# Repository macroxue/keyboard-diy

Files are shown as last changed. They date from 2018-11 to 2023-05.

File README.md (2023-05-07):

# Darknight: DIY 60% Split Keyboard
[Ergonomic Design](#ergonomic-design) -
[Layout](#layout) -
[Parts](#parts) -
[Tools](#tools) -
[Construction](#construction) -
[Updates](#updates)

## Ergonomic Design

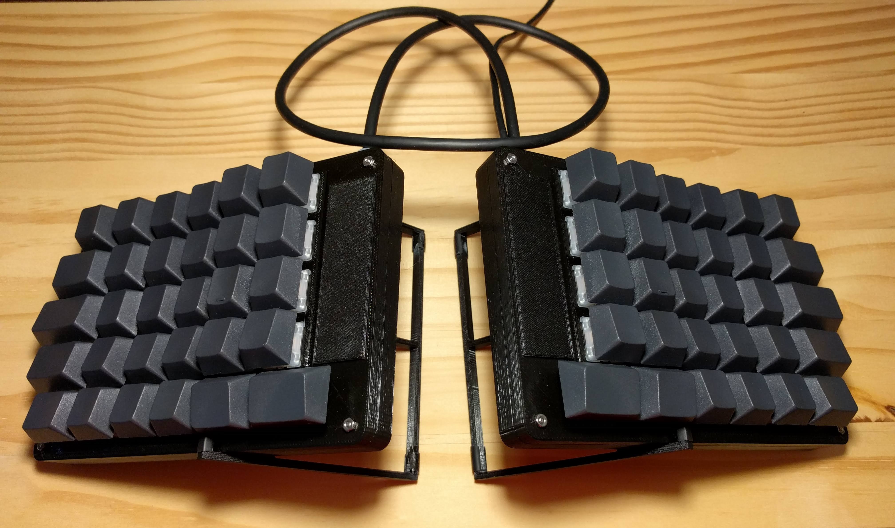
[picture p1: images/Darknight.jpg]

 * 60% keyboard for programmers, especially vim users
 * Symmetric ortholinear / matrix layout
 * Split and tentable
 * Tenting angle quickly adjustable by moving the tenting racks inwards or outwards
 * Mild contour to adapt to finger lengths, with z-staggering and cherry-profile keycaps

## Layout

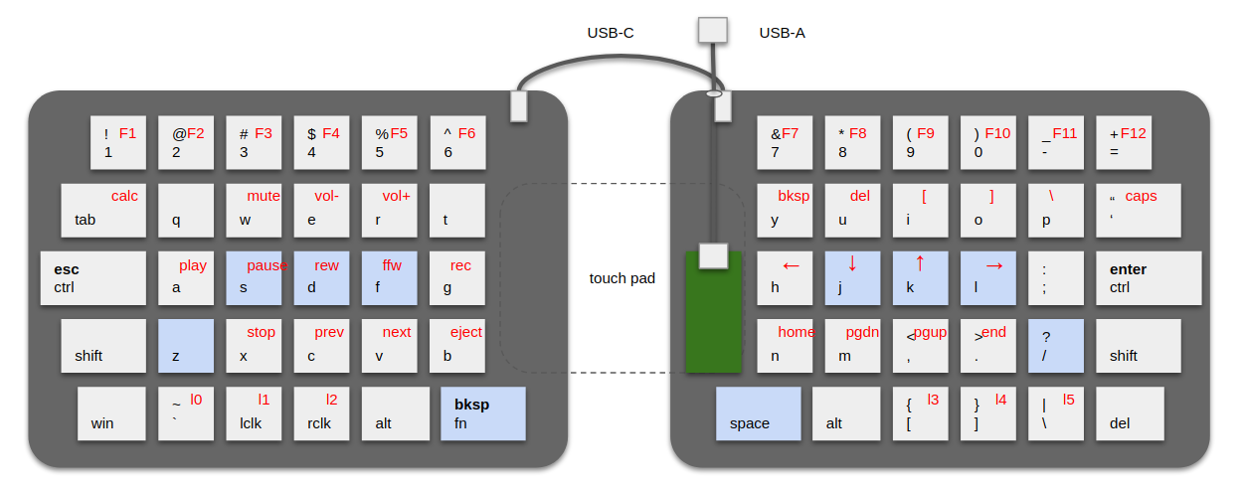
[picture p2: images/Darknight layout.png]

 * Fn key is at the home position of left thumb, which makes cursor moving keys on the right half easily accessible.
 * Ctrl and Fn keys are dual-role modifiers. When tapped, they produce Escape, Enter and Backspace instead. The only downside is that they can’t auto-repeat because they are modifiers when pressed and held. (Hint: Use Ctrl-Backspace to delete words.)
 * Left-click and right-click are at the bottom row of the left half. One can move the mouse with right hand and click on the keyboard with left hand.
 * Brackets and Backslash are at the bottom row of the right half. Single-quote is right above Enter. These changes allow the right half to have only 6 columns and mirror the left half.
 * The blue keys are the home keys of fingers at rest.

## Parts

 * 6 3D-printed case pieces and 2 tenting racks
   * Front piece, back piece and chip cover for each case
   * 8 M2x16 screws and 8 M2 nuts for assembling the cases
 * 60 Gateron red switches (or any Cherry MX compatible switches), plate mounted
 * 60 Blank PBT keycaps from a 120-piece set
   * 60 O-rings for dampening
 * One Teensy 3.2 or Teensy LC as controller
 * For handwired matrix
   * 22 AWG 6-color stranded hook-up wires
   * One 0.25mm copper sheet, 6x6 inches
   * 60 1N4148 diodes
 * One USB-C gen 2 cable (with plugs cut off) for connecting halves.
   See [issue #1](https://github.com/macroxue/keyboard-diy/issues/1).
 * One USB mini cable for connecting the keyboard to computer

## Tools

 * 3D printer
 * Soldering iron
 * Tweezers
 * Wire stripper
 * Heavy duty scissors
 * Knife
 * Nails and hammer
 * Filer
 * Multimeter

## Construction

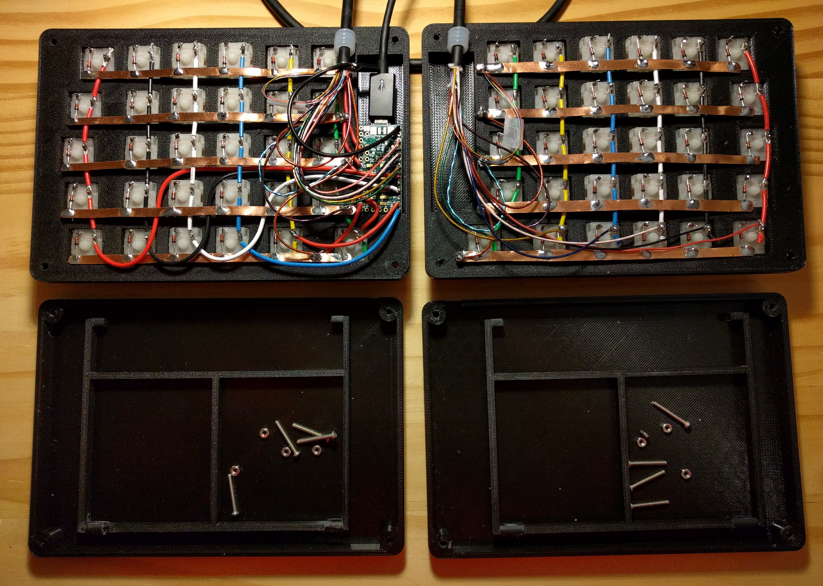
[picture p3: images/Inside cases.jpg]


### Printing cases and tenting racks: 17 hours
 * Print cases: 16 hours with PLA and 12 hours with ABS
 * Print tenting racks: 2 hours with PLA and 1.5 hours with ABS
 * Print chip covers: 10 minutes

3D models in STL format as well as the OpenSCAD file producing them are in [models](https://github.com/macroxue/keyboard-diy/tree/master/models) directory. I use FlashPrint for FlashForge Creator Pro to convert STL files to X3G files before printing them from a SD card.

There are three choices of racks. [rack-rigid.stl](https://github.com/macroxue/keyboard-diy/tree/master/models/rack-rigid.stl) is quick to print and rigid for high tenting angle. [rack-curvy.stl](https://github.com/macroxue/keyboard-diy/tree/master/models/rack-curvy.stl) is good looking but not rigid. [rack-blend.stl](https://github.com/macroxue/keyboard-diy/tree/master/models/rack-blend.stl) is good looking and rigid.

### Installing switches and keycaps: 20 minutes
 * Install switches: 10 minutes
 * Orient switches: pins are at the top half
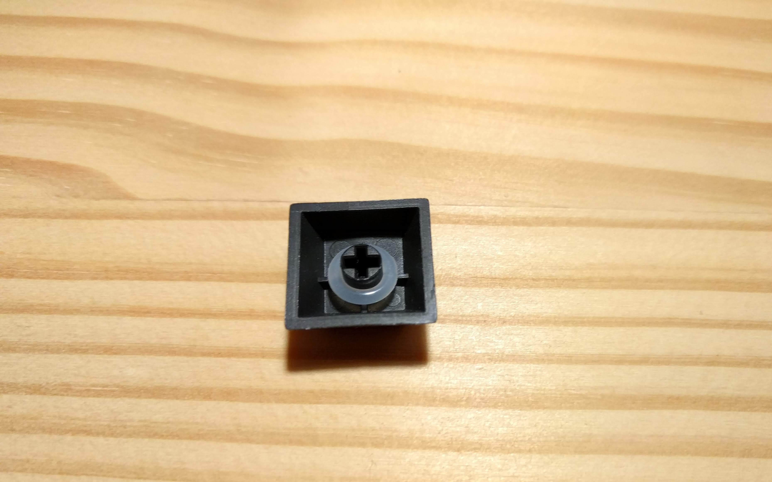
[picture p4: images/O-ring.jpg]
 * Install O-rings and keycaps: 10 minutes 

### Wiring diagrams
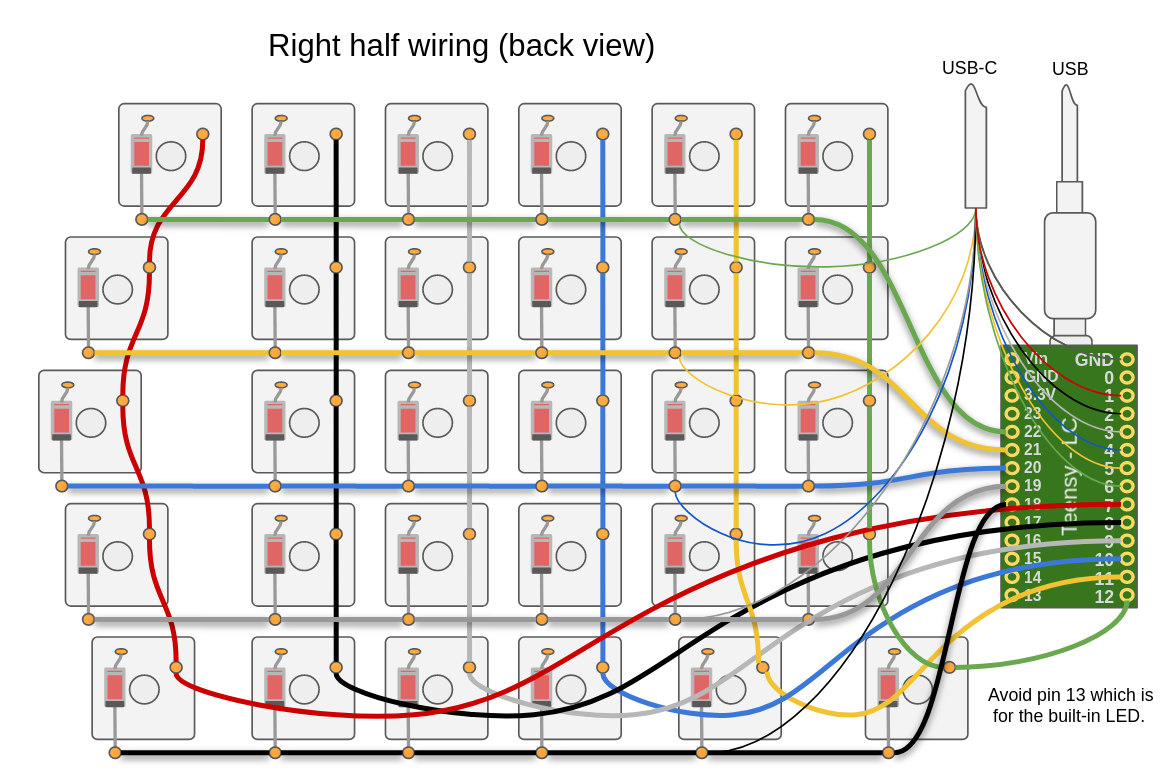
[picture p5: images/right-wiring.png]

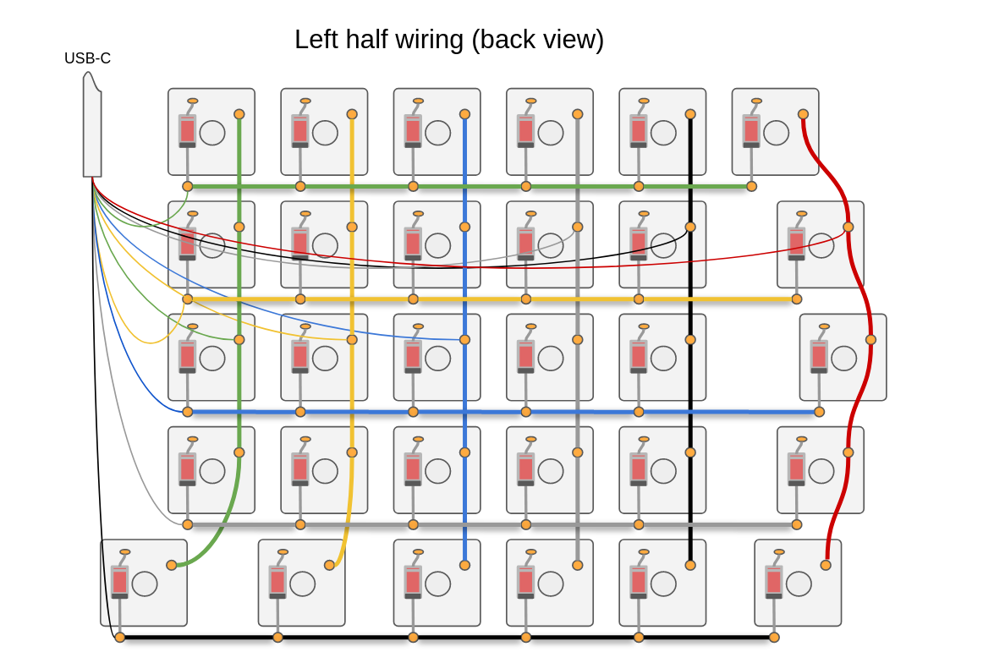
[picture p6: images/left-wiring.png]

 * Use any of the digital pins except pin 13 (LED)
 * Feel free to use pins different than what are in the diagrams

### Wiring switch columns: 2 hours, 1 for each split
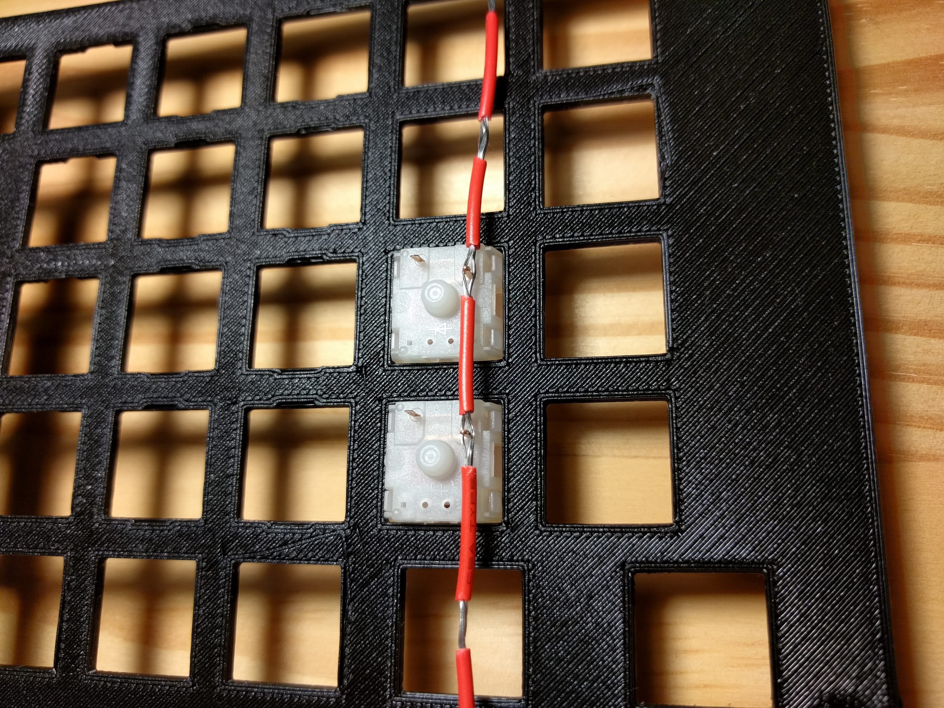
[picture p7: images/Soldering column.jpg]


 * Mark on stranded wire where column pins are
 * Use wire stripper to cut at each mark and 5mm to the right of the mark, i.e. two horizontal cuts 5mm apart at each mark
 * Make a vertical cut between the two horizontal cuts with a knife and remove the insulation to expose the strands
 * Split strands into two parts so a column pin can get through
 * Solder the wire to the pins

### Wiring switch rows and diodes: 4 hours, 2 for each split
 * Cut 3~4mm wide stripe off copper sheet with heavy-duty scissors
 * Mark positions of row pins on the stripe
 * Drill small holes (D~=1mm) at the marks and an extra hole at the end toward the center for wiring the row to the controller
   * Use hammer and nail if no drill at hand
 * Diodes with black terminal oriented downward
   * The black terminal is inserted into a hole on the stripe and bent upward
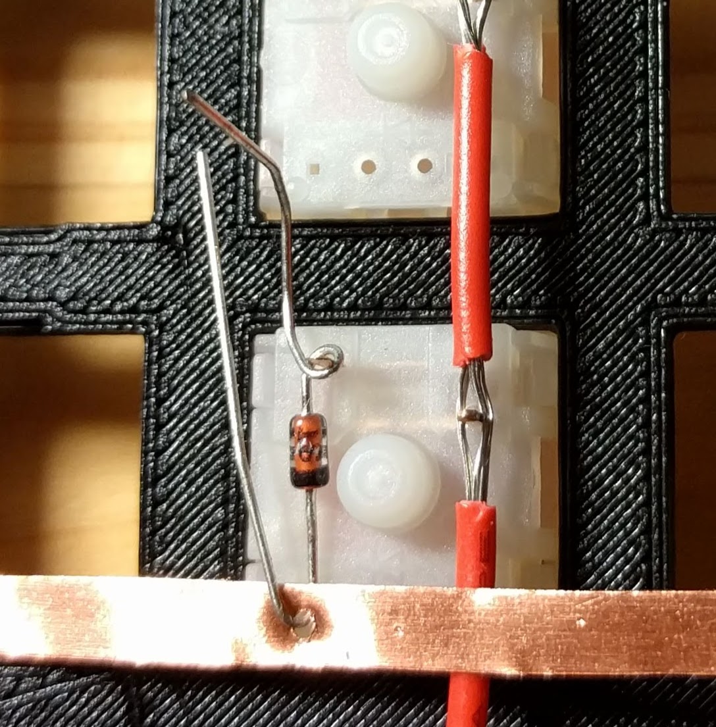
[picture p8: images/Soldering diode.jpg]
   * The other terminal is wrapped around a row pin for at least one complete circle 
 * Make sure the stripe doesn’t touch any exposed part of column wires
 * Solder diodes to row pins
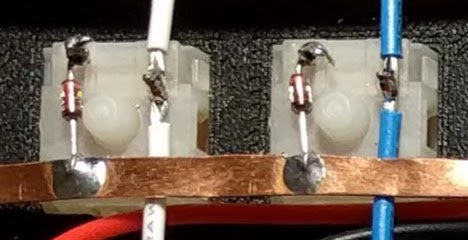
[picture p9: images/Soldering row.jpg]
 * Solder diodes to copper stripe. When solder is applied with the side (not the tip) of the iron touching the stripe, a small “flooding” area of solder creates a strong solder joint. 
 * Cut off extra length of diode terminals

### Testing and fixing: 20 minutes
 * Use a multimeter. Turn the dial to diode sign.
 * Red on column, black on row
 * Press the key at the column-row. Multimeter should read current.

### Connecting the right matrix to controller: 2 hours
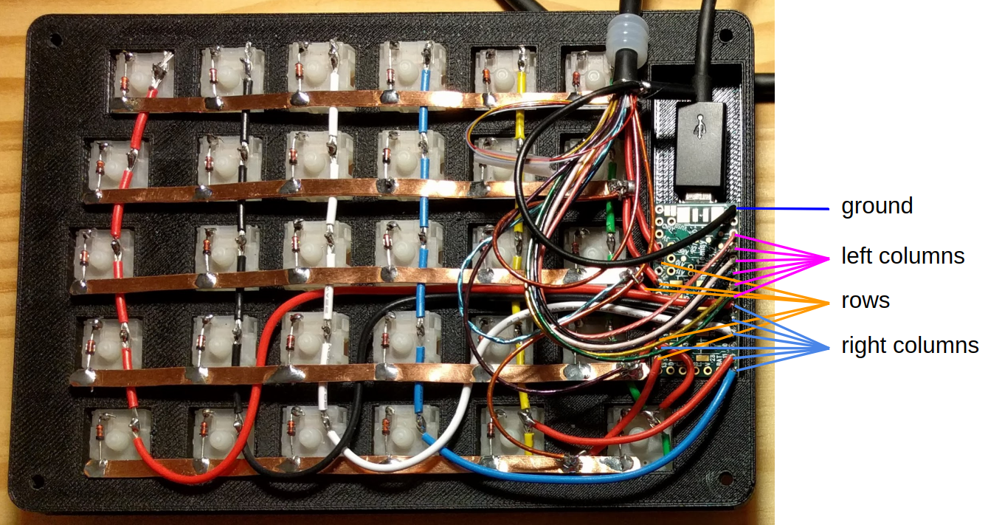
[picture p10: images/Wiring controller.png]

 * Avoid *pin 13* which is for the built-in LED
 * Figure out how to route the wires before soldering
 * Rows are routed with fairly short wires so either solid or stranded wires work
 * Columns are routed with stranded wires for flexibility
 * The controller has its program/reset button facing down so it's accessible without opening the case

### Connecting the left matrix to USB-C: 1 hour
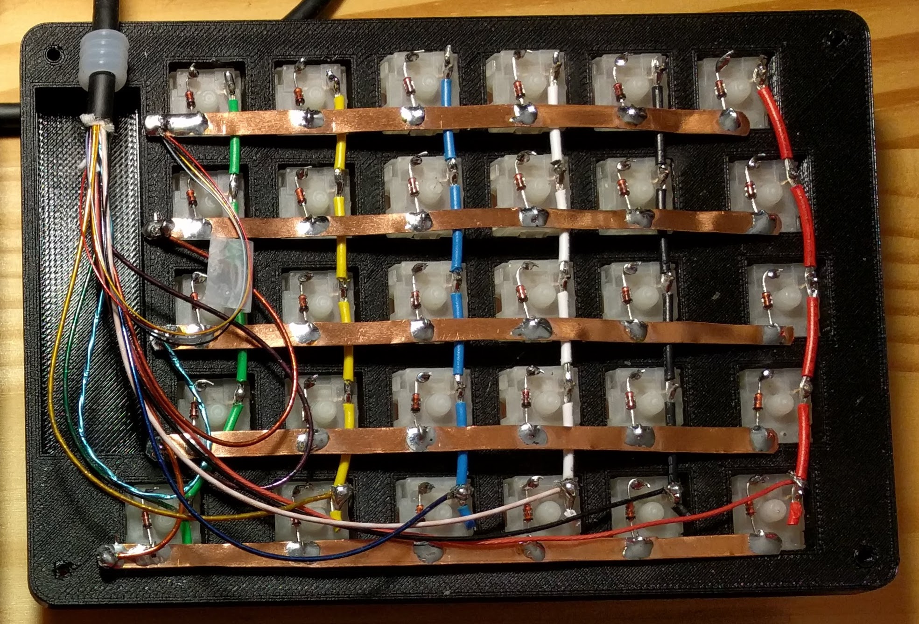
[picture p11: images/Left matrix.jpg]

 * Prepare USB-C cable
   * Cut the plugs off
   * Insert the cable into a few O-rings, which can act as stoppers
   * Mark the length to reach the furthest column
   * Make a round cut at the mark with a knife and remove the insulation
   * Remove the silver-colored mesh and paper wrap to expose wires
   * Observe 4 thin wires and 10 thick wires (2 from a twisted pair)
   * Solder 4 thin wires into one
 * Pin or tape USB-C cable so it doesn’t move around
 * Decide which wire for which column/row
 * Color coding helps, e.g. red USB-C wire to red column wire
 * Cut wires to proper lengths
 * Use soldering iron to remove insulation at the end of each wire
 * Wrap strands around a soldering joint and solder

### Connecting left and right rows: 30 minutes
 * Prepare USB-C cable to expose wires at the other end
 * Pin or tape USB-C cable so it doesn’t move around
 * Cut wires to proper lengths
 * Use soldering iron to remove insulation at the end of each wire
 * Wire rows of the left half to rows of the right half, so logically there are 5 rows.

### Connecting left columns to controller: 30 minutes
 * Ground the silver-colored mesh to GND pin of the controller. Ghost keys can pop up without this.
 * Wire columns of the left half to the controller

### Uploading firmware
 * Note down which controller pin each row/column is wired to. There are 5 rows and 12 columns. Column 0 is where left shift is and column 11 is where right shift is.
 * Plug in USB mini cable to the controller and connect the keyboard to a computer.
 * Download [Teensyduino](https://www.pjrc.com/teensy/teensyduino.html) which extends Arduino to support Teensy controllers.
 * Clone [firmware repo](https://github.com/macroxue/keyboard-firmware) on the computer.
 * Update [keyboards/darknight/darknight.ino](https://github.com/macroxue/keyboard-firmware/blob/master/keyboards/darknight/darknight.ino) with above-noted row pins and column pins.
 * Create a symbolic link in Arduino's libraries directory to the cloned firmware directory.
 * Open `darknight.ino` in Arduino IDE.
 * In the IDE, change "Tools > Board" setting to be "Teensy LC" or "Teensy 3.2/3.1" depending on the controller chip, and change "Tools > USB Type" setting to "Keyboard + Mouse + Joystick".
 * Use "Sketch > Verify/Compile" to make sure the firmware compiles fine, then use "Sketch > Upload" to upload the firmare to the controller.
 * Test the new keyboard!

It happened once that pressing any two keys among Q, W, E, R and T at the same time would also produce Tab. It was fixed by swapping the wires connecting to the first row and the second row. The exact cause is still unknown but a guess is along the line of induced current.

### Closing the cases: 10 minutes
 * Make sure USB mini cable and USB C cable fit in the cable hole
   * May need to enlarge the cable hole with a filer
 * Insert screws and fasten the cases with nuts

### Installing tenting racks: 5 minutes

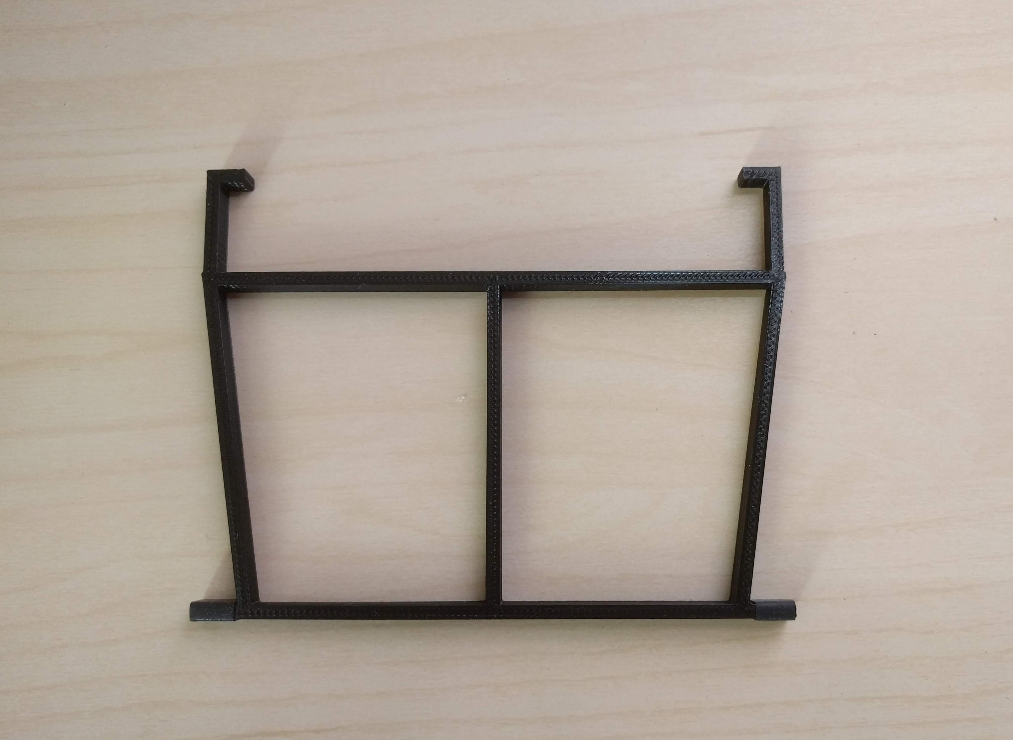
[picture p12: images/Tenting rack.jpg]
 * Cut 8mm pieces from USB-C insulation and insert rack feet into the pieces to increase friction on surface 
 * Slide each case into a rack and adjust tenting angle
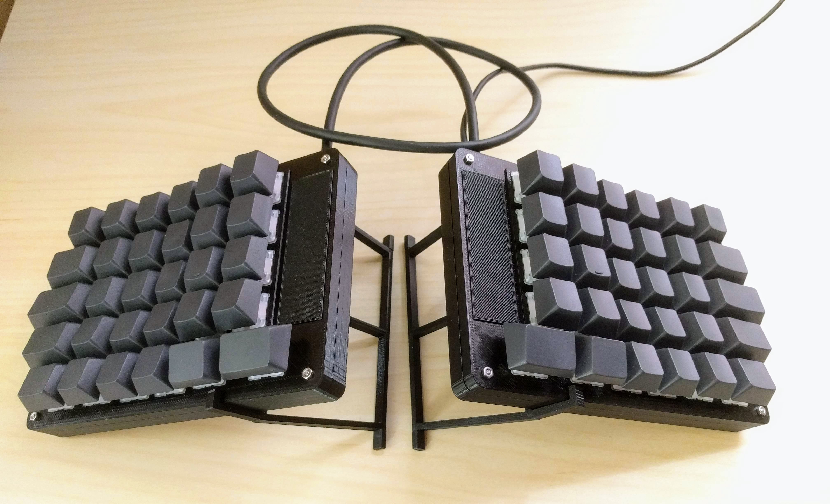
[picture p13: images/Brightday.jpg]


## Updates
### New build on 7/7/2019
Change of color scheme. Maybe call it WhiteKnight.

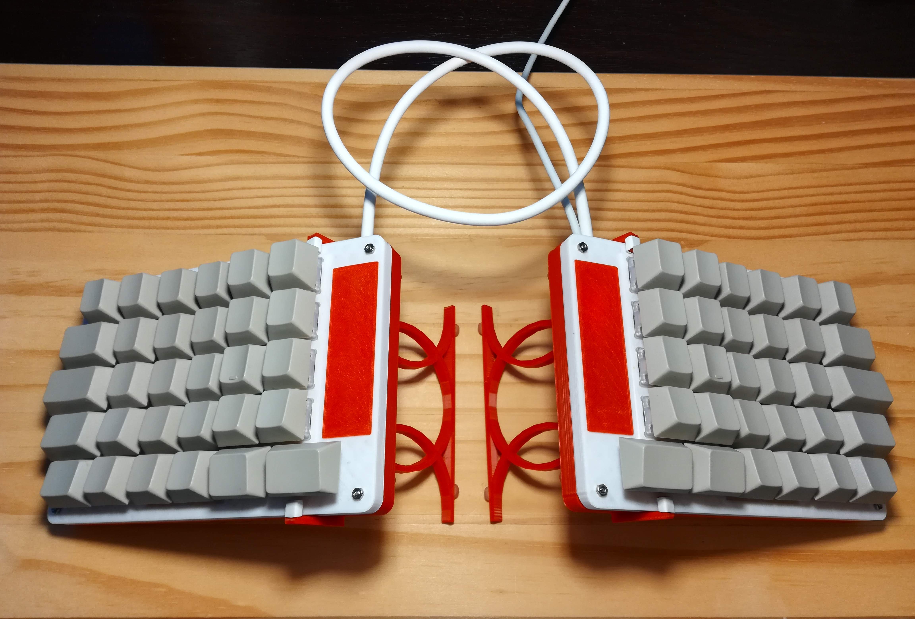
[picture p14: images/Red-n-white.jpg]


### New build on 12/30/2020
What else is better than building another keyboard in these holidays! I call this one RedBaron.

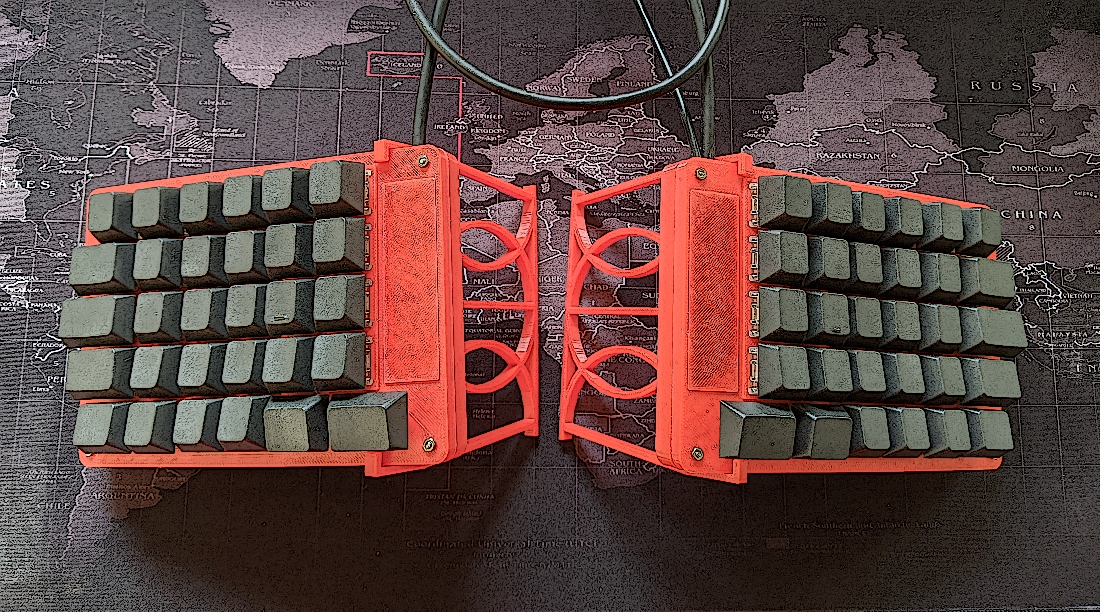
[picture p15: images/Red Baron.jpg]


Now I have three such keyboards, Darknight trapped at work due to the pandemic, WhiteKnight for working at home and RedBaron for personal use.

For this build, I just used stranded wires for the matrix. It turns out to be simpler since the wires can be routed to the controller directly.

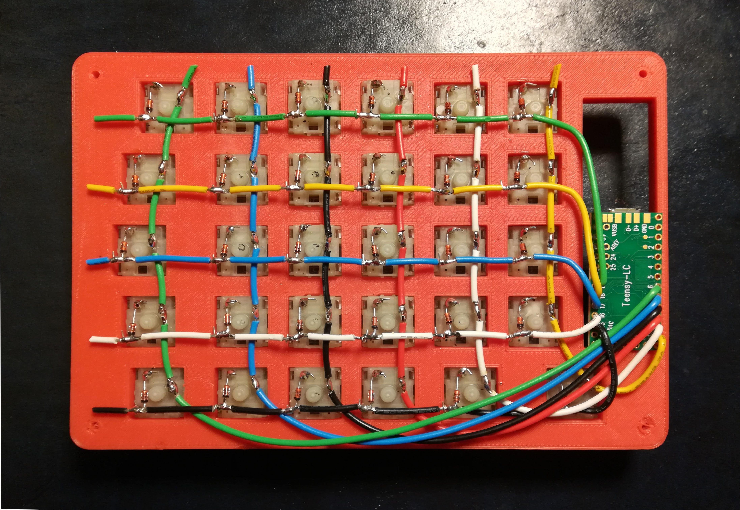
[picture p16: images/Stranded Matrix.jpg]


### High-angle tenting on 11/12/2021

A bridge connecting the two halves turns out to be a good solution for high-angle tenting. The bridge is simply the two tenting racks joined together, with small adjustments in size.

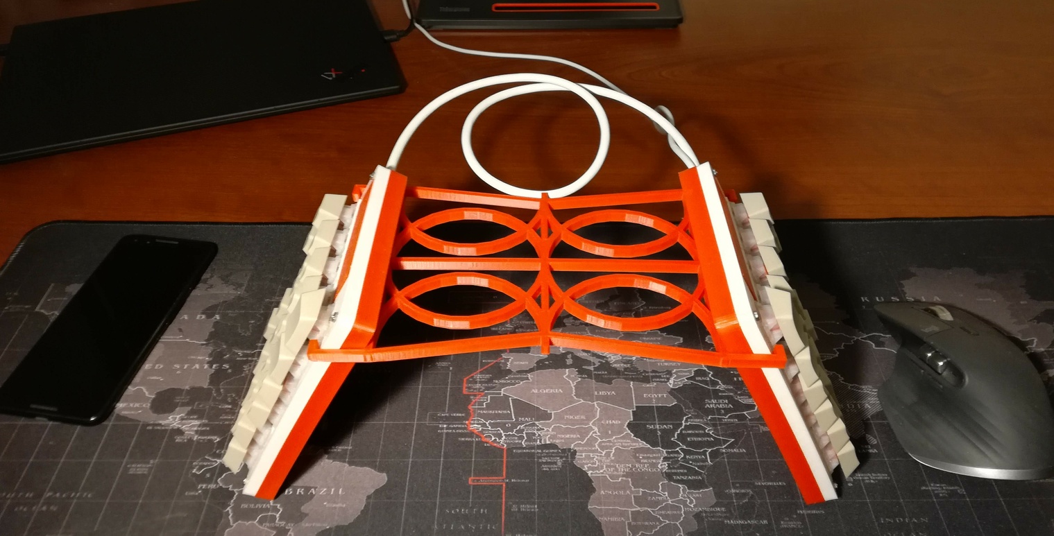
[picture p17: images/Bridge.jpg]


With a little more engineering, the entire structure can be locked by tension so it can be easily moved around.

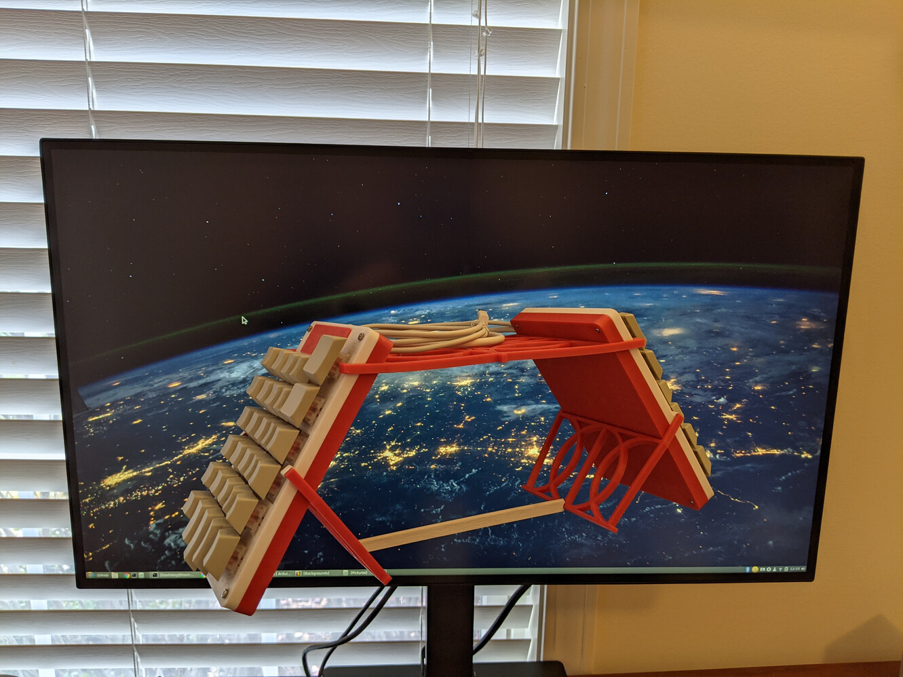
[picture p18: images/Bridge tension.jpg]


### New build on 5/7/2023

Darknight is officially missing in the office during the COVID pandemic. Site maintenance
took it as a company equipment and recycled it. After nearly 4 years of heavy use, Gateron
Red linear switches in WhiteKnight begin to fail. Tangerine is the new replacement build.

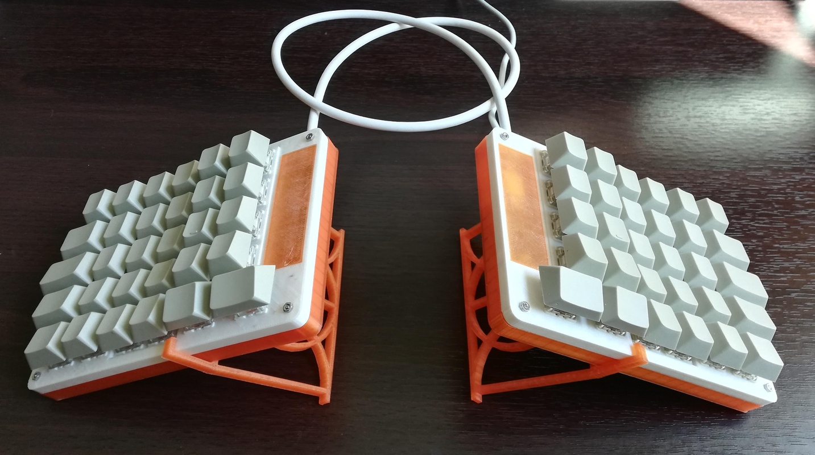
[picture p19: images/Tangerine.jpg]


One surprise is with the USB-C cable ordered from Amazon, which is thicker and has many
more ground wires than before. I just leave them unused.

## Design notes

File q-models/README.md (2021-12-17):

# Little Pumpkin

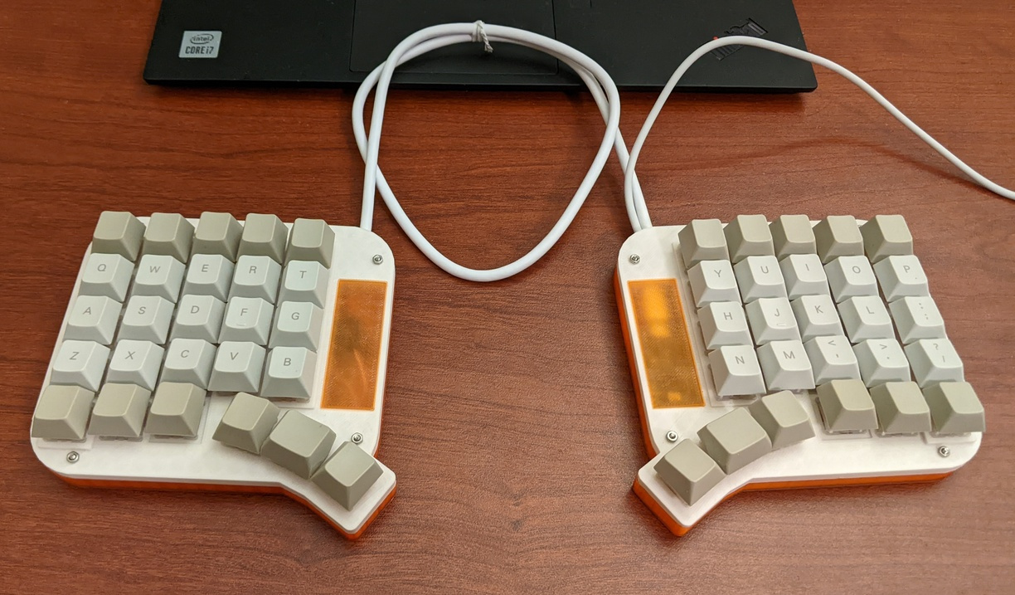
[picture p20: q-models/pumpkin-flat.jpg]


My daily driver has been a 60% split keyboard. As holidays come, I feel a bit
adventuous for a 50% one, so here is Little Pumpkin, named after its color
theme. It removes the two outer pinky columns from the 60% and adds two thumb
keys, so the load is more reasonably distributed. This is probably the smallest
layout I can work with since I need the numbers in the base layer.

*The thumb arc* - only three keys but still pretty hard to get right. I end up with
negatively tiled keycaps to make thumbs rest on them more comfortably and
modified 1.25u key in the middle to reduce gaps between keys. Still I don't
think I got everything right there.

*Staggering* - added z-staggering where each column's elevation is based on the
finger length. This is different than column staggering which I would call
y-staggering. Combining y- and z-staggering gives most benefits of a keywell.

*Wiring* - handwired with a single Teensy LC controller. You can see some guts
through the two semi-transparent windows. One reason is that I'm just
old-school and not mass-producing keyboards. Another reason is that PCBs don't
handle z-staggering well.

*Shape* - almost rectangular so I can keep using the same simple tenting
mechanism.  Recently I've seen a lot irregularly shaped boards popping up. They
are aesthetically appealing but could be impossible to tent. :)

*Keymapping* - only the base layer and one functional layer. Handling more than
two is too much mental gymnastics for me, so hats off to people who can work
with a 30% keyboard. There is enough space for two controls, two shifts and
two alts but I have to make them dual-role modifiers to accommodate more keys.

*Verdict* - a good toy for now. The thumb arc is unsatisfactory. Column
staggering could be a mistake, e.g. "in" becomes harder to type because they
are further away from each other.

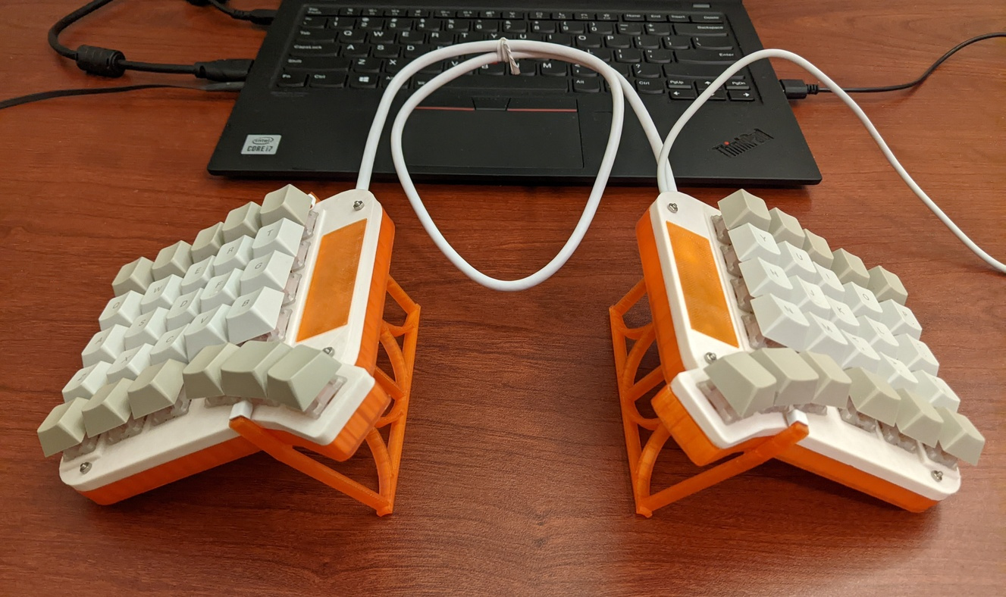
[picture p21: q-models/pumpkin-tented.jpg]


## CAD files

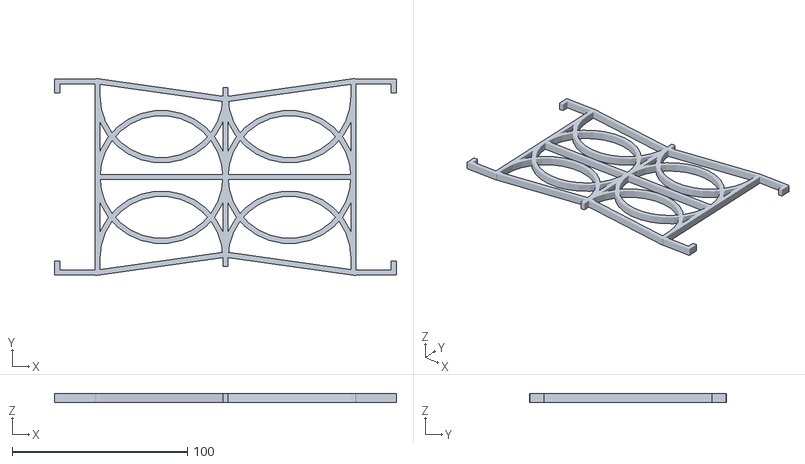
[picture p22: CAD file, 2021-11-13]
models/rack-bridge.stl
195.0 x 112.4 x 5.00

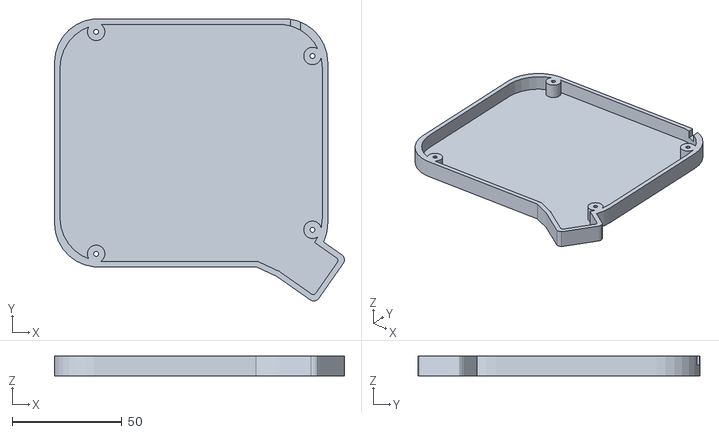
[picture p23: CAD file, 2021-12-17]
q-models/left-back.stl
132.3 x 128.7 x 9.01

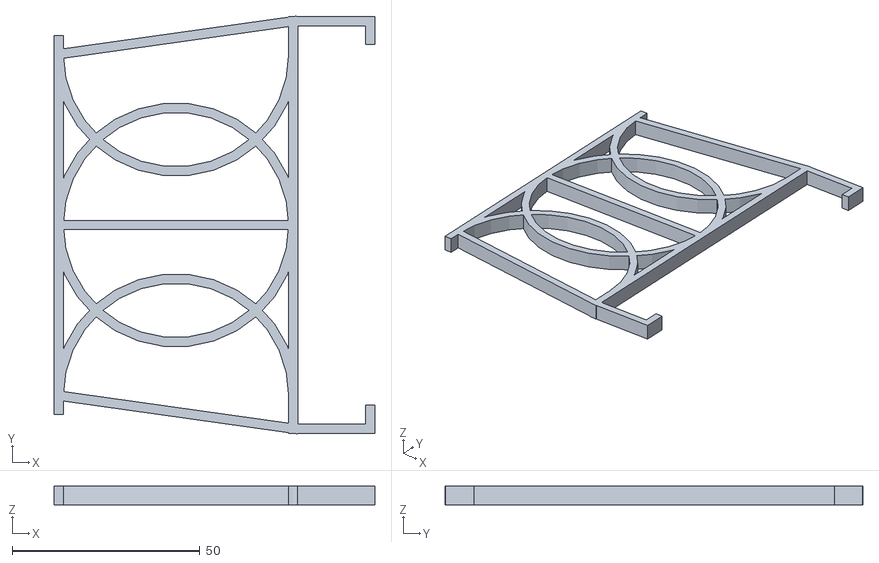
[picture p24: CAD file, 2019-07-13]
models/rack-blend.stl
85.5 x 111.3 x 5.00

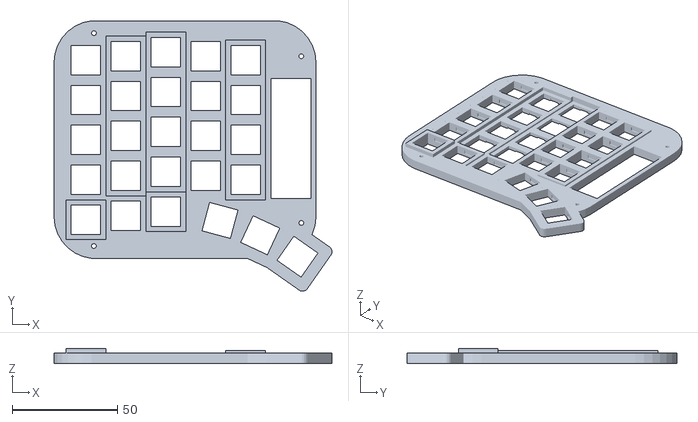
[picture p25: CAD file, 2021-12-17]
q-models/left-front.stl
132.3 x 128.7 x 7.03

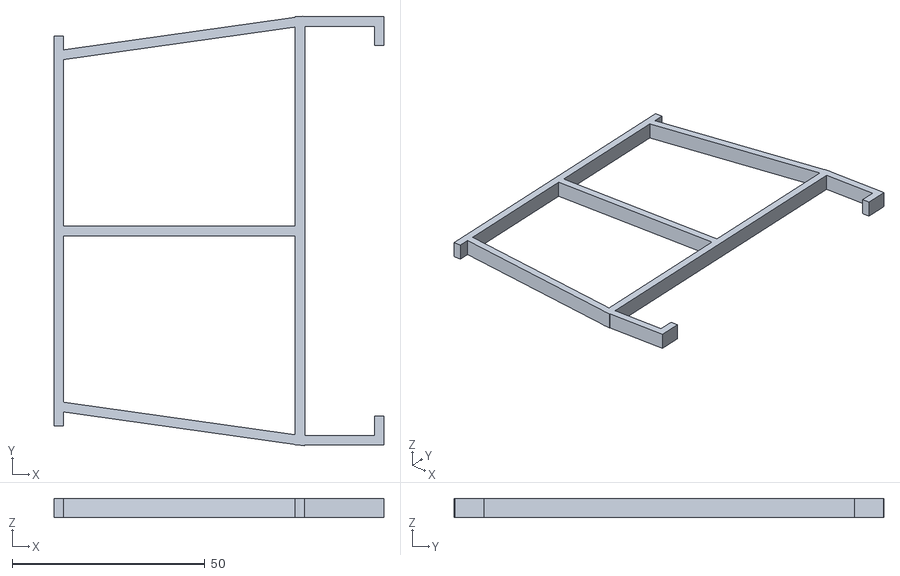
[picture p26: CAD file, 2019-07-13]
models/rack-rigid.stl
85.5 x 111.3 x 5.00

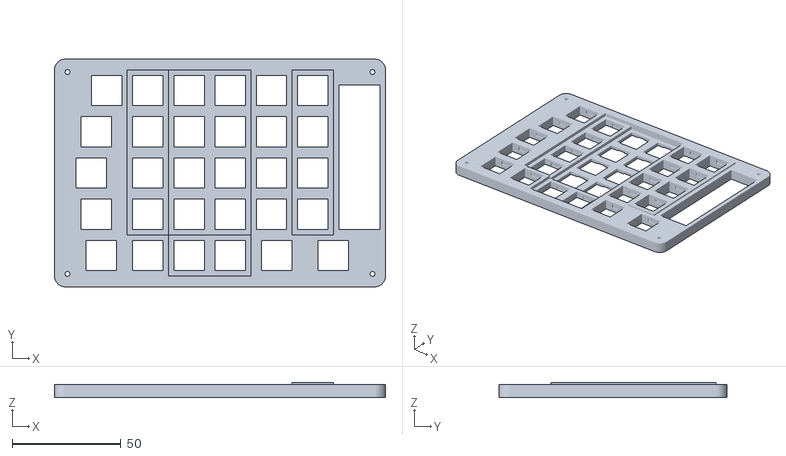
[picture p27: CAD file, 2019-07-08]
models/left-front.stl
152.5 x 104.9 x 7.03

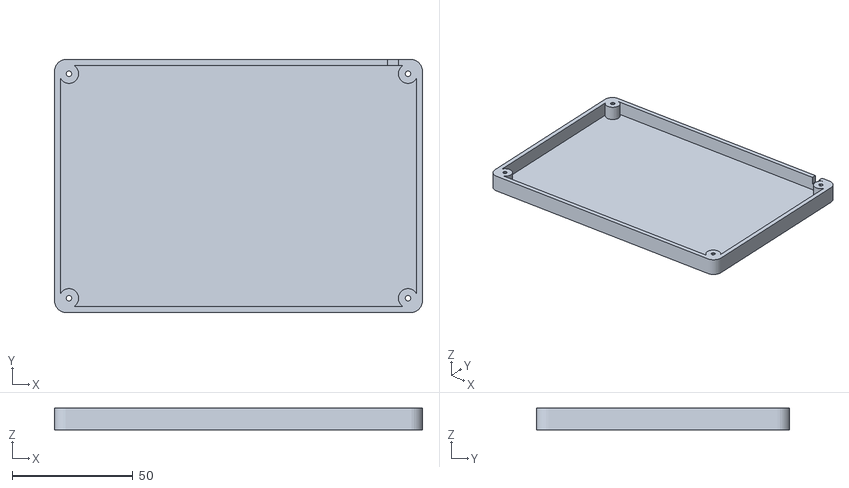
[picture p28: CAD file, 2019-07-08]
models/left-back.stl
152.5 x 104.9 x 9.01

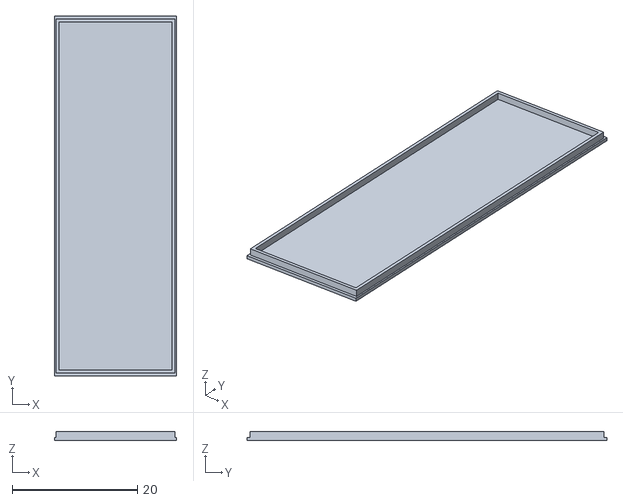
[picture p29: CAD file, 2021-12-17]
q-models/chip-cover.stl
19.5 x 57.5 x 1.50

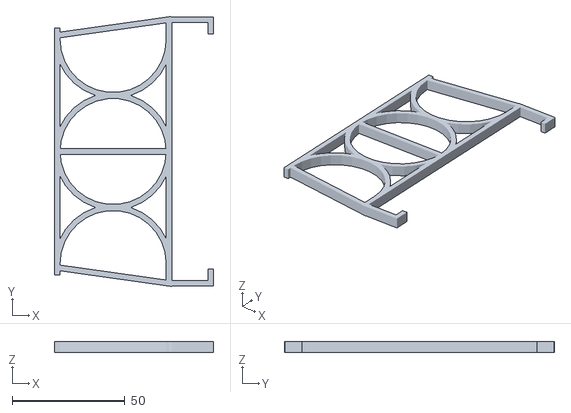
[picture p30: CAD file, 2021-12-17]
q-models/rack.stl
70.5 x 119.6 x 5.00

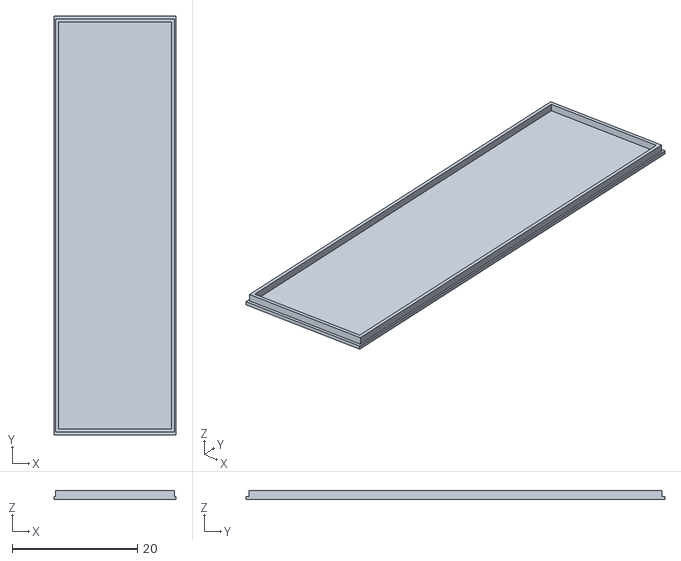
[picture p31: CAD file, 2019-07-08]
models/chip-cover.stl
19.5 x 67.0 x 1.50

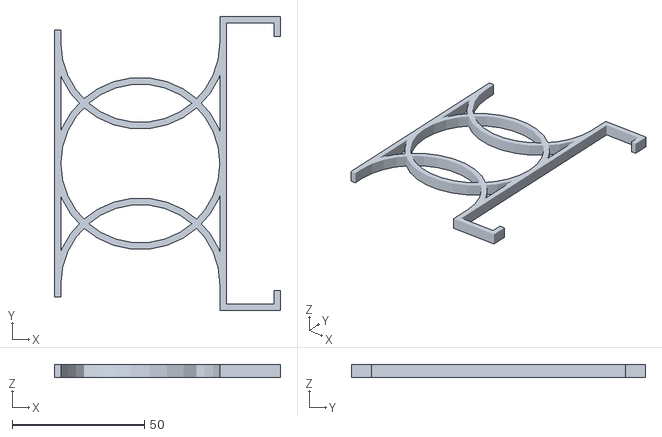
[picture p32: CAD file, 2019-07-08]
models/rack-curvy.stl
85.5 x 111.0 x 5.00

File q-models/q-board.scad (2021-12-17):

$fs=1;   // fragment length for circle
d=0.01;  // delta for extra cut

kd=19;  // key distance
cw=14;  // chamber width
ch=7.5;  // chamber height

mpt=1.5; // mount plate thickness
chw=5;   // clip hole width
chh=2;   // clip hole height
chd=0.6; // clip hole depth

thw=3.0; // teensy house width

module teensy(x,y,z) {
  tl=36;  // teensy length
  tw=18;  // teensy width
  th=4;   // teensy height
  tbh=1;  // teensy board height
  tcl=6;  // teensy connector length
  tcw=8;  // teensy connector width
  tch=3;  // teensy connector height

  translate([x*kd, y*kd, z*kd]) rotate([0,90,180]) {
    color("green") cube([tbh,tl,tw]);
    color("white") translate([tbh,-1,tw/2-tcw/2]) cube([tch,tcl,tcw]);
  }
}

module case(left=false) {
  border = 2.5;
  length = 6.3*kd;
  width = 5.7*kd;
  x_shift = 0.5*cw;
  y_shift = 1.3*cw;
  corner = 20;
  wiring_hole = 6;
  support_width = 3.5;
  sink_unit = 1;
  thickness = 5;
  fastner_shift = 8.5;
  screw_radius = 0.8+0.4;
  nut_radius = 2.0+0.4;

  key_pos = [
    [5.3,1.5,1,-1,0],[5.4,2.5,1,0,0],[5.5,3.5,1,3,0],[5.4,4.5,1,2,0],[5.3,5.5,1,0,0],
    [4.3,1.5,1,-1,0],[4.4,2.5,1,0,0],[4.5,3.5,1,3,0],[4.4,4.5,1,2,0],[4.3,5.5,1,0,0],
    [3.3,1.5,1,-1,0],[3.4,2.5,1,0,0],[3.5,3.5,1,3,0],[3.4,4.5,1,2,0],[3.3,5.5,1,0,0],
    [2.3,1.5,1,-1,0],[2.4,2.5,1,0,0],[2.5,3.5,1,3,0],[2.4,4.5,1,2,0],[2.3,5.5,1,0,0],
                                     [1.5,3.5,1,1,0],[1.4,4.5,1,0,0],[1.3,5.5,1,-2,0],
    //[-0.04,0.60,1,1.5,45],[0.66,1.35,1,1.75,30],[1.15,2.25,1,2,15],
    [0.23,0.48,1,0,35],[0.79,1.325,1,0,25],[1.20,2.25,1,0,15],
    //[0.375,0.365,1,0,30],[0.87,1.27,1,0,20],[1.20,2.25,1,0,10],
  ];
  screws = [
    [fastner_shift - 4, fastner_shift + 6],
    //[fastner_shift - 5, fastner_shift + 8],
    [fastner_shift - 4, width - fastner_shift - 6],
    [length - fastner_shift - 8, width - fastner_shift + 5],
    [length - fastner_shift - 8, fastner_shift - 5],
  ];

  module key(row,col,size,sink=0,angle=0) {
    translate([kd*(col+(size-1)/2)+border,kd*row+border,-sink*sink_unit-d]) {
      rotate([0,0,angle]) {
        translate([-(kd-cw)/2,-(kd-cw)/2,thickness+d]) cube([kd+d,kd+d,sink*sink_unit+d*2]);
        translate([0,0,-10]) cube([cw,cw,20]);
        translate([cw/2-chw/2,-chd,thickness-chh-mpt]) cube([chw,cw+chd*2,chh]);
      }
    }
  }

  module keys() {
    for (k=key_pos) key(k[0],k[1],k[2],k[3],k[4]);
  }

  module key_raise(row,col,size,sink=0) {
    if (sink < 0)
    translate([kd*(col+(size-1)/2)+border,kd*row+border,0]) {
      translate([-(kd-cw)/2,-(kd-cw)/2,thickness+d]) cube([kd+d,kd+d,-sink*sink_unit+d*2]);
    }
  }

  module key_raises() {
    for (k=key_pos) key_raise(k[0],k[1],k[2],k[3]);
  }

  module key_expansion(row,col,size,sink,angle,height,extra,extra_right) {
    if (angle != 0)
    translate([kd*(col+(size-1)/2)+border,kd*row+border,0]) {
      rotate([0,0,angle]) {
        translate([-extra/4,-extra/4]) minkowski() {
          cube([cw+extra/2+extra_right,cw+extra/2,height]);
          cylinder(r=extra/4,h=d);
        }
      }
    }
  }

  module key_expansions(height,extra,extra_right=0) {
    for (k=key_pos) key_expansion(k[0],k[1],k[2],k[3],k[4],height,extra,extra_right);
  }

  module chip_house() {
    translate([0.5*kd-border,kd*2.2+(kd-cw)/2,-d*2]) cube([kd,kd*thw,thickness+d*4]);
  }

  module writing_left(row,col,height) {
    content = "收";
    font = "WenQuanYi Micro Hei";
    translate([col*kd+16,row*kd,height+thickness-d]) rotate([0,180,0])
      linear_extrude(height+2*d) {
        text(content, font = font, size = 10);
      }
  }

  module writing_right(row,col,height) {
    content = "获";
    font = "WenQuanYi Micro Hei";
    translate([col*kd,row*kd,thickness-d])
      linear_extrude(height+2*d) {
        text(content, font = font, size = 10);
      }
  }

  module front() {
    module screw_holes() {
      for (s=screws)
        translate([s[0]+x_shift, s[1]+y_shift,-d])
          cylinder(r=screw_radius, h=thickness+d*3);
    }

    difference() {
      union() {
        translate([corner-border+x_shift,corner-border+y_shift,0]) minkowski() {
          cube([length+border*2-corner*2,width+border*2-corner*2,thickness]);
          cylinder(r=corner,h=d);
        }
        key_expansions(thickness,cw*0.8);
      }
      keys();
      screw_holes();
      chip_house();
    }
    difference() {
      key_raises();
      keys();
    }
    //if (left) writing_left(4.2,0,2);
    //else writing_right(4.2,0,2);
  }

  module back() {
    thickness = 1.5;
    front_sink = 3;
    hole_depth = border*4+2*d;

    module cable_hole(w,h) {
      translate([10+x_shift,width-3+y_shift,border+ch-h-0.5])
        cube([w,border+6,h+2*d]);
    }

    module usb_hole(w,h) {
      translate([1.25*kd+2,width+corner+border-d,ch+border-h])
        cube([w,border+2*d,h+2*d]);
    }

    module screw_holes() {
      for (s=screws) {
        translate([s[0]+x_shift, s[1]+y_shift,-d])
          union() {
            cylinder(r=screw_radius, h=ch+thickness+d*2);
            cylinder(r=nut_radius, h=1+d*2);
          }
      }
    }

    module plate() {
      difference() {
        union() {
          difference() {
            union() {
              translate([corner-border+x_shift,corner-border+y_shift,0]) minkowski() {
                cube([length+border*2-corner*2,width+border*2-corner*2,ch+thickness]);
                cylinder(r=corner,h=d);
              }
              key_expansions(ch+thickness,cw*0.8);
            }
            union() {
              translate([corner+x_shift,corner+y_shift,thickness]) minkowski() {
                cube([length-corner*2,width-corner*2,ch+thickness]);
                cylinder(r=corner,h=d);
              }
              translate([0,0,thickness]) key_expansions(ch+thickness,cw*0.8-border*2,.1);
            }
          }
          // base for screw hole
          for (s=screws)
            translate([s[0]+x_shift, s[1]+y_shift,0])
              cylinder(r=4, h=ch+thickness);
        }
        screw_holes();
        if (left) cable_hole(4.5,4.5);
        else cable_hole(7.5,4.5);
      }
    }

    plate();
  }

  // For rack-bridge: thickness=3; first_shelf=70; second_shelf=20;
  module rack() {
    thickness=2.5;
    extra=1;
    rack_width=width+border*2+thickness*2+extra;
    first_shelf=47;
    second_shelf=16;
    rack_height=first_shelf+second_shelf+thickness*3;
    hook=5;

    module rack2d() {
      difference() {
        square([rack_height, rack_width]);
        translate([thickness,-d])
          square([first_shelf,rack_width+d*2]);
        translate([thickness*2+first_shelf,thickness])
          square([second_shelf,rack_width-thickness*2]);
        translate([rack_height-thickness-d,thickness+hook])
          square([thickness+d*2,rack_width-thickness*2-hook*2]);
        translate([-d,-d]) square([thickness+d*2,hook+d*2]);
        translate([-d,rack_width-hook-d]) square([thickness+d*2,hook+d*2]);
      }

      module arc() {
        difference() {
          circle(d=first_shelf + thickness*2);
          circle(d=first_shelf);
          translate([-first_shelf/2-thickness,0])
            square([first_shelf+thickness*2, first_shelf/2+thickness]);
        }
      }

      module curvy() {
        translate([first_shelf/2+thickness,rack_width-hook*2]) arc();
        translate([first_shelf/2+thickness,rack_width/2]) rotate([180,0,0]) arc();
        translate([first_shelf/2+thickness,hook*2]) rotate([0,0,180]) arc();
        translate([first_shelf/2+thickness,rack_width/2]) arc();
      }

      module straight() {
        angle=8;
        shift=(first_shelf+thickness)*tan(angle)+0.1;
        translate([0.5,shift]) rotate([0,0,-angle])
          square([first_shelf + thickness*2, thickness]);
        translate([0,rack_width/2-thickness/2])
          square([first_shelf + thickness*2, thickness]);
        translate([0.5,rack_width-thickness-shift]) rotate([0,0,angle])
          square([first_shelf + thickness*2, thickness]);
      }

      //translate([first_shelf/2+thickness/2,first_shelf/2+hook])
      //  square([thickness,rack_width-first_shelf-hook*2]);

      curvy();
      straight();
    }
    linear_extrude(height=5) rack2d();
  }

  //front();
  //translate([0,0,-ch-20]) back();
  translate([0,13,-ch-40]) rack();
}

module chip_cover() {
  wall=0.5;
  depth=1.0;
  extra=0.2;
  translate([-2.5,kd*2.2+2.5,0]) {
    cube([kd+wall,kd*thw+wall,wall]);
    translate([wall/2,wall/2+extra,-depth]) difference() {
      cube([kd,kd*thw-extra*2,depth]);
      translate([wall,wall,-d]) cube([kd-wall*2,kd*thw-extra*2-depth,depth+d*2]);
    }
  }
}

translate([-4*kd,-3*kd,0]) {
  case(left=false);
  // For rack-bridge: translate([3,0,0]) mirror([1,0,0]) case(left=true);
  //translate([-kd,0,0]) mirror([1,0,0]) case(left=true);
  //translate([-2,0,0]) rotate([0,180,0]) teensy(0,3.5,0);
  //rotate([0,180,0]) chip_cover();
}

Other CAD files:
q-models/right-front.stl
q-models/right-back.stl
models/right-front.stl
models/right-back.stl
models/darknight.scad

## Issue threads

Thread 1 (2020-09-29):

Link to USB-C cable used in pictures?

yarnay, 2020-09-29:
I am concerned I will cut open a usb-c cable and find out it is not color coded.

Also is it important if it gen 2 or not? Or did you just test gen 2?

Thanks and regards,

macroxue, 2020-10-01:
I've been using only "USB 3.1 Type-C Gen 2 Cable" made by Cable Matters. I suspect early Gen may miss some wires but I have no proof.
https://www.amazon.com/Cable-Matters-USB-IF-Certified-Delivery/dp/B01L0F6IK4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

Closed 2021-02-27.

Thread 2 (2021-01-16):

Track point

MagicRB, 2021-01-16:
Have you thought about adding a trackpoint? Because in my opinion what you currently have looks really good and I wish to make one someday, though if it had a trackpoint it would be the best 3dprinted keyboard by a long shot. btw https://www.youtube.com/channel/UCSsm4h2ccJMdR6bsAFyIu6A might be worth looking into,

macroxue, 2021-01-30:
Good suggestion. There is room for adding a trackpoint right above the space/backspace key at the center so it's easily reachable by a thumb. I will look into this and check out the channel. Thanks!

macroxue, 2021-02-27:
There is nowhere to find a trackpoint module. The only way seems to be getting a Thinkpad keyboard with trackpoint.

I tried a cheap mini joystick module. It can work as a mouse in principle but the movement is like zigzag on the x-axis and y-axis, not smooth at all. Maybe a better module is all I need.

MagicRB, 2021-02-27:
It may be possible to rip one from a thinkpad, that would be amazing to have a track point on there

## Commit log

2018-11-04 Update controller wiring image for pin usage
2019-07-08 Add 3D models
    [chip-cover.stl, darknight.scad, left-back.stl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]
2019-07-13 Add two more rigid racks
    [darknight.scad, rack-blend.stl, rack-curvy.stl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]
2021-11-13 Add rack-bridge for high tenting
    [darknight.scad, rack-bridge.stl]
2021-11-25 Tenting by tension
2021-12-02 Use plate mounted switches
2021-12-17 Add Little Pumpkin
    [chip-cover.stl, left-back.stl, left-front.stl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]
2021-12-21 Avoid LED pin for the matrix
2021-12-21 Add wiring diagrams
2021-12-21 Move wiring diagrams up
